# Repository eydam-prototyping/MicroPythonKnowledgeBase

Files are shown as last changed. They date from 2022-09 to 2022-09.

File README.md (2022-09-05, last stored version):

# Ethernet am ESP32 mit Micropython

Der ESP32 enthält bereits einen MAC-Controller, sodass nur noch ein PHY-Controller benötigt wird, um Ethernet am ESP32 zu nutzen. Für einige PHY-Controller gibt es im ESP-IDF bereits eine API, die auch in MicroPython verfügbar ist. Konkret sind das die PHY-Controller:

 - DP83848
 - IP101
 - LAN8720
 - RTL8201

Ich habe nachfolgend eine Schaltung mit dem RTL8201 erstellt. Dieser Chip ist bei JLCPCB verfügbar. Hier meine Überlegungen zum Anschluss:

## MII/RMII Interface

Im Beispiel ist die Variante CONFIG_ETH_RMII_CLK_INPUT gewählt. Dabei stellt der PHY-Controller das Clock-Signal zur Verfügung. Dieses Signal muss dann zu GPIO 0 am ESP32 geführt werden. Über GPIO 0 wird aber auch der Boot-Modus gewählt. Daher sollte der PHY (und damit auch das Clock-Signal) erst nach dem Boot-Vorgang gestartet werden. Dies kann über den Pin PHYRSTB am PHY gesteuer werden.

Pin RTL8201 | Richtung | Anschluss          | Erklärung 
------------|----------|--------------------|----------
TXC         | Out      | GPIO 0             | Transmit Clock, wird vom PHY zur Verfügung gestellt
TXEN        | In       | GPIO 21            | Transmit Enable, festgelegt, nicht änderbar
TXER        | In       | -                  | Transmit Error, für RMII nicht benötigt
TXD[0]      | In       | GPIO 19            | Transmit Data, festgelegt, nicht änderbar
TXD[1]      | In       | GPIO 22            | Transmit Data, festgelegt, nicht änderbar
TXD[2]      | In       | -                  | Transmit Data, für RMII nicht benötigt
TXD[3]      | In       | -                  | Transmit Data, für RMII nicht benötigt
RXC         | Out      | -                  | Receive Clock, für RMII nicht benötigt
COL         | Out      | -                  | Collision Detected, für RMII nicht benötigt
CRS         | In/Out   | GPIO 27            | Carrier Sense, festgelegt, nicht änderbar
RXDV        | Out      | 4.7kOhm PullUp     | Receive Data Valid, für RMII nicht benötigt
RXD[0]      | Out      | GPIO 25            | Receive Data, festgelegt, nicht änderbar
RXD[1]      | Out      | GPIO 26            | Receive Data, festgelegt, nicht änderbar
RXD[2]/INTB | Out      | GPIO x             | Receive Data, für RMII nicht benötigt, alternativ Interrupt, wenn sich Linkstatus ändert
RXD[3]      | Out      | -                  | Receive Data, für RMII nicht benötigt
RXER        | Out      | 4.7kOhm PullDown   | Receive error, für RMII nicht benötigt

## Serial Management

Pin RTL8201 | Richtung | Anschluss          | Erklärung 
------------|----------|--------------------|----------
MDC         | In       | GPIO 23            | Management Data Clock, default, änderbar
MDIO        | In/Out   | GPIO 18            | Management Data Input/Output, default, änderbar

## Clock

Pin RTL8201 | Richtung | Anschluss          | Erklärung 
------------|----------|--------------------|----------
X1          | In       | 25MHz Crystal      | Crystal
X2          | Out      | 25MHz Crystal      | Crystal

## Network Interface

Pin RTL8201 | Richtung | Anschluss          | Erklärung 
------------|----------|--------------------|----------
MDI+[0]     | In/Out   | Netzwerkbuchse     | Transmit Output
MDI-[0]     | In/Out   | Netzwerkbuchse     | Transmit Output
MDI+[1]     | In/Out   | Netzwerkbuchse     | Receive Input
MDI-[1]     | In/Out   | Netzwerkbuchse     | Receive Input
LED0        | Out      | Netzwerkbuchse     | Konfigurierbar, siehe Datenblatt
LED1        | Out      | Netzwerkbuchse     | Konfigurierbar, siehe Datenblatt

## Versorgung und Reset

Pin RTL8201 | Richtung | Anschluss                  | Erklärung 
------------|----------|----------------------------|----------
PHYRSTB     | In       | GPIO x, 10kOhm PullDown    | Enable, siehe Erklärung unter MII/RMII-Interface

```
import machine
import network
import time

l = network.LAN(mdc = machine.Pin(23), mdio = machine.Pin(18), phy_type = network.PHY_RTL8201, phy_addr=0)
l.active(True)
print("Eth interface active")

old_state = l.status()
while(True):
    if old_state != l.status():
        if l.status() == network.ETH_CONNECTED:
            print("ETH_CONNECTED")
        if l.status() == network.ETH_DISCONNECTED:
            print("ETH_DISCONNECTED")
        if l.status() == network.ETH_GOT_IP:
            print("ETH_GOT_IP")
        if l.status() == network.ETH_INITIALIZED:
            print("ETH_INITIALIZED")
        if l.status() == network.ETH_STARTED:
            print("ETH_STARTED")
        if l.status() == network.ETH_STOPPED:
            print("ETH_STOPPED")
        old_state = l.status()
    time.sleep(0.1)
```

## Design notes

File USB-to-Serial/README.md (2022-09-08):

# USB-to-Serial Converter

In vielen elektronischen Schaltungen im Hobby-Bereich wird UART genutzt und der CH340G ist ein weit verbreiteter, günstiger IC, der eine Serielle Schnittstelle per USB zur Verfügung stellt. 

Ich habe hier einmal versucht, die Begriffe auseinanderzuhalten, allerdings ist das gar nicht so einfach:

## UART

Steht für Universal Asynchronus Receiver/Transmitter. In diesem Protokoll werden Regeln definiert, wie serielle Daten zwischen Sender und Empfänger ausgetauscht werden. Es werden für zwei Datenleitungen (Tx, Rx) verwendet. Die Tx (Transmit)-Leitung des Senders muss mit der Rx (Receive)-Leitung des Empfängers verbunden werden. Spannungspegel sind nicht vorgeschrieben, allerdings sind 3,3 bzw. 5V üblich.

Die Daten werden in Rahmen (Frames) übertragen. Da es kein gemeinsames Taktsignal gibt, müssen beide Teilnehmer vorher auf die gleiche Datenrate (Baudrate) eingestellt werden. Weiterhin müssen Einstellungen zu Start-/Stop-Bits, Paritätsbits und Anzahl der Datenbits getroffen werden.

## RS232

RS232 ist an UART angelehnt, aber noch ein bisschen mehr. RS232 war ursprünglich für die Kommunikation mit einem Modem gedacht. Das Mehr gegenüber UART ist unter anderem:

 - Spannungen sind definiert:
   - -15 V bis -3 V sind eine logische 1
   - 3 V bis 15 V sind eine logische 0
 - es gibt neben den beiden Datenleitungen noch Steuerleitungen:
   - DCD, Data Carrier Detect
   - DTR, Data Terminal Ready
   - DSR, Data Set Ready
   - RTS, Request to Send
   - CTS, Clear to Send
   - RI, Ring Indicator

[https://de.wikipedia.org/wiki/RS-232](https://de.wikipedia.org/wiki/RS-232)

## CH340G

Der CH340G ist ein USB-to-UART-Converter, unterstützt aber weitere Modem-Signale. 

Pin CH340G | Richtung | Erklärung 
-----------|----------|-----------
VCC        | Power    | 3,3V oder 5V, 100nF Kondensator, Versorgungsspannung entspricht IO-Spannung
V3         | Power    | Bei VCC=3,3V: mit VCC verbinden, bei VCC=5V: mit 100nF Kondensator verbinden
GND        | Power    |  
XI, XO     | Clock    | 12MHz Quarz
TXD        | Out      | Transmit
RXD        | In       | Receive
~CTS       | In       | Clear to Send (active low)
~DSR       | In       | Data Set Ready (active low)
~RI        | In       | Ring Indicator (active low)
~DCD       | In       | Data Carrier Detect (active low)
~DTR       | Out      | Data Terminal Ready (active low)
~RTS       | Out      | Request to Send (active low)
RS232      | In       | Zusätzliche RS232 Funktionalität aktivieren (high), z.B. Rx-Pin invertieren

[https://www.mpja.com/download/35227cpdata.pdf](https://www.mpja.com/download/35227cpdata.pdf)

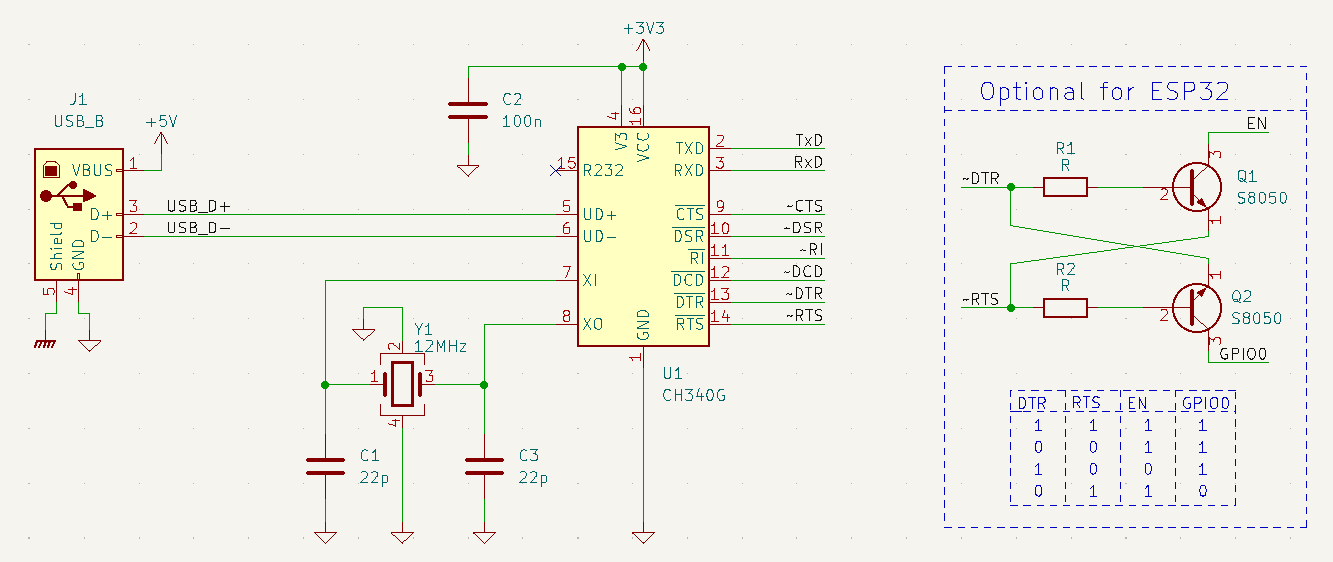
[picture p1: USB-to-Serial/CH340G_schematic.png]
CH340G Schematic


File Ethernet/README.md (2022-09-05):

# Ethernet am ESP32 mit Micropython

Der Ethernet-Treiber besteht aus zwei Teilen: dem MAC- und dem PHY-Controller.

Der ESP32 enthält bereits einen MAC-Controller, sodass nur noch ein PHY-Controller benötigt wird, um Ethernet am ESP32 zu nutzen. Für einige PHY-Controller gibt es im ESP-IDF bereits eine API, die auch in MicroPython verfügbar ist. Konkret sind das die PHY-Controller:

 - DP83848
 - IP101
 - LAN8720
 - RTL8201

Für die Kommunikation zwischen MAC und PHY wird das MII (Media Independent Interface) bzw. RMII (Reduced Media Independent Interface) genutzt. Das MII besteht aus: 
 - Transmitter Signals:
   - TXC (Transmit Clock)
   - TXD0-3 (Transmit Data Bit 0-3)
   - TXEN (Transmit Enable)
   - TXER (Transmit Error)
 - Receiver Signals:
   - RXC (Receive Clock)
   - RXD0-3 (Receive Data Bit 0-3)
   - RXDV (Receive Data Valid)
   - RXER (Receive Error)
   - CRS (Carrier Sense)
   - COL (Collision Detect)
 - Management Signals:
   - MDIO (Management Data)
   - MDC (Management Data Clock)

Das beim RMII entfallen einige Signale:
 - Transmit und Receive Clock werden durch ein Signal ersetzt (REF_CLK)
 - die Clock-Frequenz wird von 25 auf 50 MHz angehoben, dafür werden nur 2 statt 4 Transmit bzw. Receive Data Bits benötigt
 - RXDV und CRS werden gemultiplexed
 - COL wird komplett entfernt

Damit ist die Anzahl der benötigten Pins von 18 auf 9 reduziert.

Ich habe nachfolgend eine Schaltung mit dem RTL8201 erstellt. Dieser Chip ist bei JLCPCB verfügbar. Hier meine Überlegungen zum Anschluss:

## MII/RMII Interface

Im Beispiel stellt der PHY das Clock-Signal zur Verfügung. Das ist in der aktuellen MicroPython-Version (19.1) die einzige Möglichkeit. Dieses Signal muss dann zu GPIO 0 am ESP32 geführt werden. Über GPIO 0 wird aber auch der Boot-Modus gewählt. Daher sollte der PHY (und damit auch das Clock-Signal) erst nach dem Boot-Vorgang gestartet werden. Dies kann über den Pin PHYRSTB am PHY gesteuer werden.

Pin RTL8201 | Richtung | Anschluss          | Erklärung 
------------|----------|--------------------|----------
TXC         | Out      | GPIO 0             | Transmit Clock (Reference Clock), wird vom PHY zur Verfügung gestellt
TXEN        | In       | GPIO 21            | Transmit Enable, festgelegt, nicht änderbar
TXER        | In       | -                  | Transmit Error, für RMII nicht benötigt
TXD[0]      | In       | GPIO 19            | Transmit Data, festgelegt, nicht änderbar
TXD[1]      | In       | GPIO 22            | Transmit Data, festgelegt, nicht änderbar
TXD[2]      | In       | -                  | Transmit Data, für RMII nicht benötigt
TXD[3]      | In       | -                  | Transmit Data, für RMII nicht benötigt
RXC         | Out      | -                  | Receive Clock, für RMII nicht benötigt
COL         | Out      | -                  | Collision Detected, für RMII nicht benötigt
CRS         | In/Out   | GPIO 27            | Carrier Sense, festgelegt, nicht änderbar
RXDV        | Out      | 4.7kOhm PullUp     | Receive Data Valid, für RMII nicht benötigt
RXD[0]      | Out      | GPIO 25            | Receive Data, festgelegt, nicht änderbar
RXD[1]      | Out      | GPIO 26            | Receive Data, festgelegt, nicht änderbar
RXD[2]/INTB | Out      | GPIO x             | Receive Data, für RMII nicht benötigt, alternativ Interrupt, wenn sich Linkstatus ändert (noch nicht getestet)
RXD[3]      | Out      | -                  | Receive Data, für RMII nicht benötigt
RXER        | Out      | 4.7kOhm PullDown   | Receive error, für RMII nicht benötigt

## Serial Management

Pin RTL8201 | Richtung | Anschluss          | Erklärung 
------------|----------|--------------------|----------
MDC         | In       | GPIO 23            | Management Data Clock, default, änderbar
MDIO        | In/Out   | GPIO 18            | Management Data Input/Output, default, änderbar

## Clock

Pin RTL8201 | Richtung | Anschluss          | Erklärung 
------------|----------|--------------------|----------
X1          | In       | 25MHz Crystal      | Crystal
X2          | Out      | 25MHz Crystal      | Crystal

## Network Interface

Pin RTL8201 | Richtung | Anschluss          | Erklärung 
------------|----------|--------------------|----------
MDI+[0]     | In/Out   | Netzwerkbuchse     | Transmit Output
MDI-[0]     | In/Out   | Netzwerkbuchse     | Transmit Output
MDI+[1]     | In/Out   | Netzwerkbuchse     | Receive Input
MDI-[1]     | In/Out   | Netzwerkbuchse     | Receive Input
LED0        | Out      | Netzwerkbuchse     | Konfigurierbar, siehe Datenblatt
LED1        | Out      | Netzwerkbuchse     | Konfigurierbar, siehe Datenblatt

## Versorgung und Reset

Pin RTL8201 | Richtung | Anschluss                  | Erklärung 
------------|----------|----------------------------|----------
PHYRSTB     | In       | GPIO x, 10kOhm PullDown    | Enable, siehe Erklärung unter MII/RMII-Interface

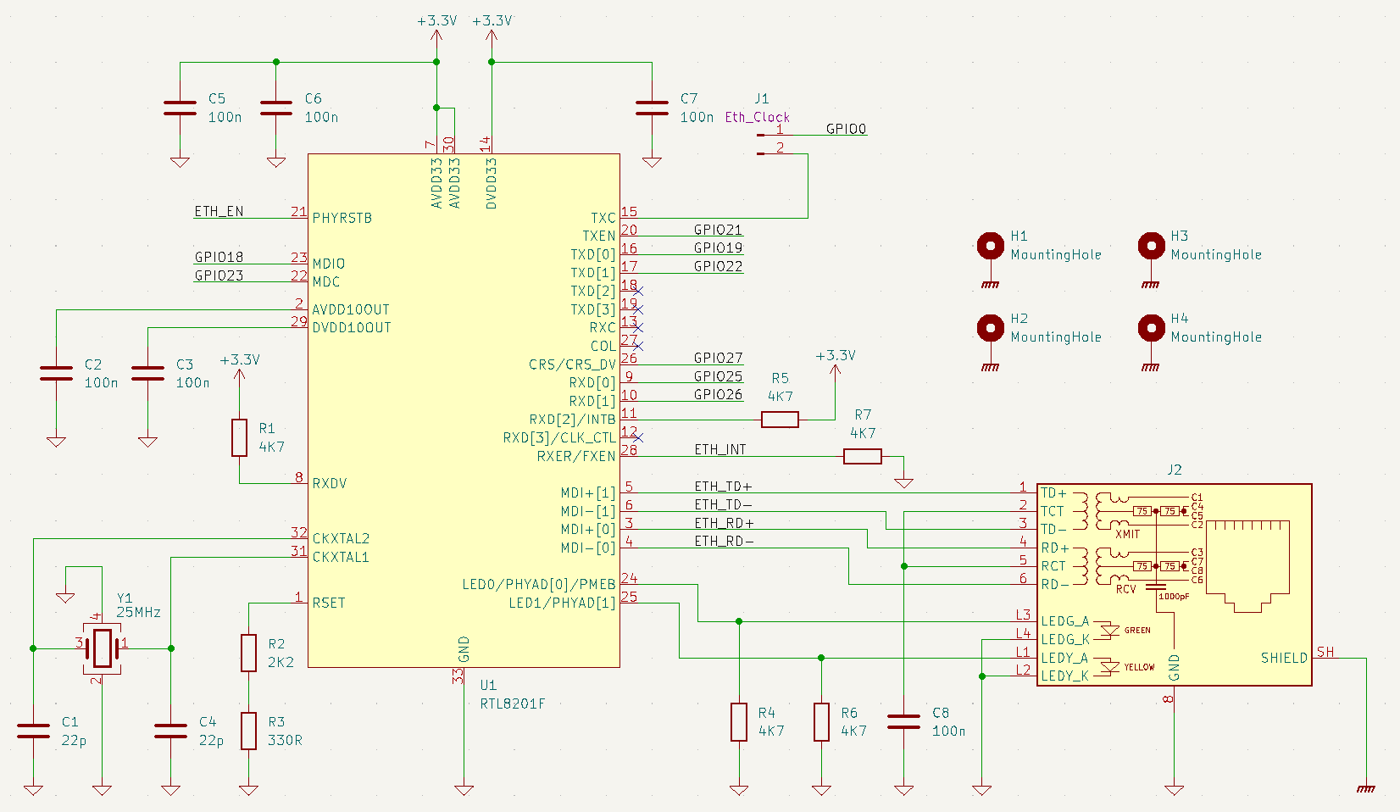
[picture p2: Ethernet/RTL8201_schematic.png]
RTL8201 Schematic


Das REF_CLK-Signal wird hier über einen Jumper schaltbar gemacht. Dieser sollte eigentlich nicht nötig sein. Falls aber der das Clock-Signal verhindert, dass der ESP32 in den Boot-Modus gelangt, kann der Jumper geöffnet werden und der ESP32 sollte nicht mehr gestört werden. 

Hinweis zum Shield-Pin: Nach meinen Nachforschungen soll die Schirmung des Steckers mit dem Gehäuse verbunden werden. Ich mache das hier über die Befestigungsbohrungen.

[https://datasheet.lcsc.com/lcsc/1809191828_Realtek-Semicon-RTL8201F-VB-CG_C45044.pdf](https://datasheet.lcsc.com/lcsc/1809191828_Realtek-Semicon-RTL8201F-VB-CG_C45044.pdf)

[https://docs.espressif.com/projects/esp-idf/en/latest/esp32/api-reference/network/esp_eth.html](https://docs.espressif.com/projects/esp-idf/en/latest/esp32/api-reference/network/esp_eth.html)

[https://github.com/espressif/esp-idf/tree/master/examples/ethernet](https://github.com/espressif/esp-idf/tree/master/examples/ethernet)

[https://en.wikipedia.org/wiki/Media-independent_interface](https://en.wikipedia.org/wiki/Media-independent_interface)

[https://electronics.stackexchange.com/questions/215138/how-to-connect-usb-ethernet-shields-to-chassis-or-digital-grounds](https://electronics.stackexchange.com/questions/215138/how-to-connect-usb-ethernet-shields-to-chassis-or-digital-grounds)

# MicroPython Code

Hier ein kurzes Beispiel, wie das Ethernet-Interface in MicroPython aktiviert wird:

```
import machine
import network
import time

l = network.LAN(mdc = machine.Pin(23), mdio = machine.Pin(18), phy_type = network.PHY_RTL8201, phy_addr=0)
l.active(True)
print("Eth interface active")

old_state = l.status()
while(True):
    if old_state != l.status():
        if l.status() == network.ETH_CONNECTED:
            print("ETH_CONNECTED")
        if l.status() == network.ETH_DISCONNECTED:
            print("ETH_DISCONNECTED")
        if l.status() == network.ETH_GOT_IP:
            print("ETH_GOT_IP")
        if l.status() == network.ETH_INITIALIZED:
            print("ETH_INITIALIZED")
        if l.status() == network.ETH_STARTED:
            print("ETH_STARTED")
        if l.status() == network.ETH_STOPPED:
            print("ETH_STOPPED")
        old_state = l.status()
    time.sleep(0.1)
```
